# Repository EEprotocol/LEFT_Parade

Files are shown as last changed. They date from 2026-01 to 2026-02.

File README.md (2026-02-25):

[Japanese docs](./README_ja.md)
# LEFT Parade Project

This is a so-called *left-hand device*.  
You can also use it with your right hand.  
It is intended for situations where you use a pen display tablet or similar device with one of your hand and want to trigger macros with the other hand.

## TL;DR
navigate
## Specifications
- Connectivity is **Bluetooth only**. Wired connections are not supported.  
  This limitation is due to the ESP32-C3; however, by using a board such as the ESP32-S3 that supports USB HID, wired operation can be implemented.
- A battery can be installed (3.7 V Li-ion).  
  Connect it directly to the battery terminals on the surface of the ESP32-C3.
- Up to **80 different macros** can be configured using simultaneous key presses  
  (Arduino IDE is required to configure the macros).
- ~~To enable the above behavior, commands are sent **when the key switch is released**, not when it is pressed.~~  
- 2 mode implimented switched by the push switch in the rotary encoder:
    1. **Combination Mode**
        In this mode, you can assign 80 macros for the combination of multiple keys. The command is send to PC when you release the keys.
    2. **Fast Attack Mode**
        The number of assignment decline to 8 (same as the number of keys), but the command is send when you push the keys. You can use this mode if you mind the delay.

## Bill of Materials
| Component | Price (JPY) |
|:---|---:|
| PCB | 110 |
| Rotary encoder | 550 |
| Knob | 324 |
| ESP32-C3 | 1,080 |
| Keycap | 70 |
| Key socket | 160 |
| Key switch | 330 |
| Battery | 450 |
| (SN74HC139N) | 135 |
| DIP socket (8 × 2 rows) | 135 |
| **Total** | **3,344** |

## Installation  
### Hardware
#### Circuit Diagram
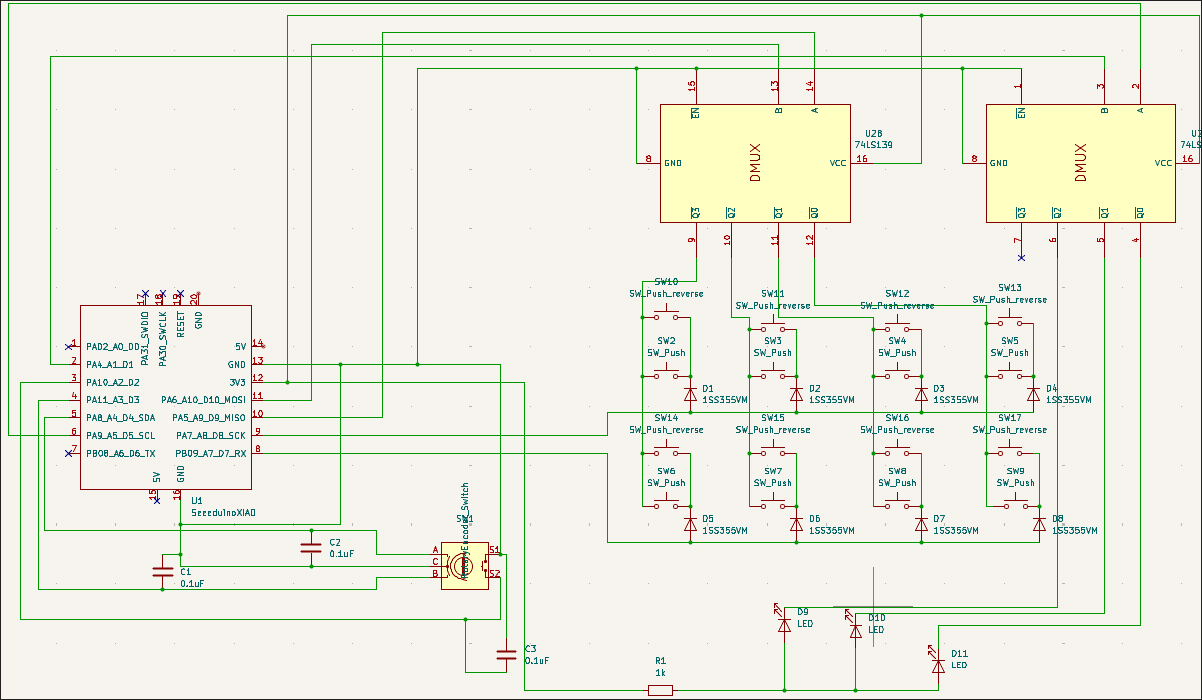
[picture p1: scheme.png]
circuit scheme Circuit Scheme

The annotation of the parts on the PCB corresponds to the circuit diagram.  
**I made a place for the LED D11, but system does not use it.**
#### soldering map
circuit soldering map
If you make this device as Left hand device, you solder on the parts surronded by **red and purple line**,
and If you make it as right hand device, solder on the parts with **purple and blue line**.
The component mounting side aligns with the side marked with the respective part indicators.

### Software
1. Install Arduino IDE on your PC, e.g.  
```yay -S arduino-ide```  

2. Install library [Mystfit/ESP32-BLE-CompositeHID](https://github.com/Mystfit/ESP32-BLE-CompositeHID).

3. Upload to `leftandmechv5_PCB/leftandmechv5_PCB.ino` to ESP32-C3.

## Macros
You can set the macro in the preamble of the `.ino` scripts.

```cpp
const uint8_t KC_SAVE[] = { 0x01, KEY_S };
const uint8_t KC_COPY[] = { 0x01, KEY_C };
const uint8_t KC_PASTE[] = { 0x01, KEY_V };
const uint8_t KC_DELETE[] = { 0x4c };
const uint8_t KC_m[] = { KEY_M };
const uint8_t KC_UNDO[] = { 0x01, KEY_Z };
const uint8_t KC_ESC[] = { KEY_ESC };
const uint8_t KC_UP[] = { KEY_UP };
const uint8_t KC_DOWN[] = { KEY_DOWN };
const uint8_t KC_LEFT[] = { KEY_LEFT };
const uint8_t KC_RIGHT[] = { KEY_RIGHT };
const uint8_t KC_PAGE_NEXT[] = { 0x01, KEY_RIGHT };
const uint8_t KC_PAGE_BACK[] = { 0x01, KEY_LEFT };
```
The list of `uint8_t` refers the operation s.t. Ctrl+S, ESC, or Delete. This list of macro is commonly used in the two mode.
In the list, terms of keys except the last term is regarded as modifier keys s.t. Alt, Ctrl or Shift.

### 1. Combination Mode
For this mode, you can set the assignment with `keymap[]`.
```cpp
const keyMapEntry keymap[] = {
  { 1, { KC_SAVE, 2 } },
  { 54, { KC_ESC, 1 } },
  { 4, { KC_COPY, 2 } },
  { 7, { KC_PASTE, 2 } },
  { 2, { KC_DELETE, 1 } },
  { 6, { KC_m, 1 } },
  { 28, { KC_UNDO, 2 } },
  { 18, { KC_UP, 1 } },
  { 9, { KC_DOWN, 1 } },
  { 27, { KC_LEFT, 1 } },
  { 3, { KC_RIGHT, 1 } },
  { 8, { KC_PAGE_NEXT, 2 } },
  { 20, { KC_PAGE_BACK, 2 } }
};
```

The first number refers the keyID of the combinaiton, second string refers the macro which you defined above and the last number refers the number of the element of the list of the macro. You can calculate the keyID as following:

assignment key_assign

2 refers the upper key, 1 refers the lower key, 0 refers no pushed.
In this mode, it is prohibited to push 2 keys in a column.

### 2. Fast Attack Mode
```cpp
const keyMapEntry direct_key[] = {
  { 1, { KC_LEFT, 1 } },
  { 2, { KC_UP, 1 } },
  { 3, { KC_DOWN, 1 } },
  { 5, { KC_RIGHT, 1 } }
};
```

The key ID which plades the first number corresponds to the following assignment:

assignment key_assign

## Todo
- [x] Impliment the GAME mode which sends commnad when keys are pushed
- [x] Fabricate a PCB
- [ ] Prepare the other version: RIGHT Parade

## Special Thanks
- [Mystfit/ESP32-BLE-CompositeHID](https://github.com/Mystfit/ESP32-BLE-CompositeHID)
- [freerouting/freerouting](https://github.com/freerouting/freerouting?tab=readme-ov-file)

## Contact
If you have something to ask, please mail to [keik4656@gmail.com](keik4656@gmail.com).

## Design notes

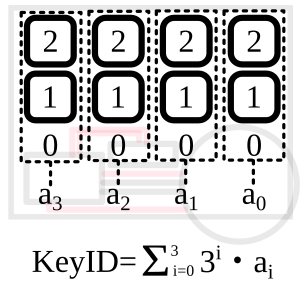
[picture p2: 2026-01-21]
assign.png

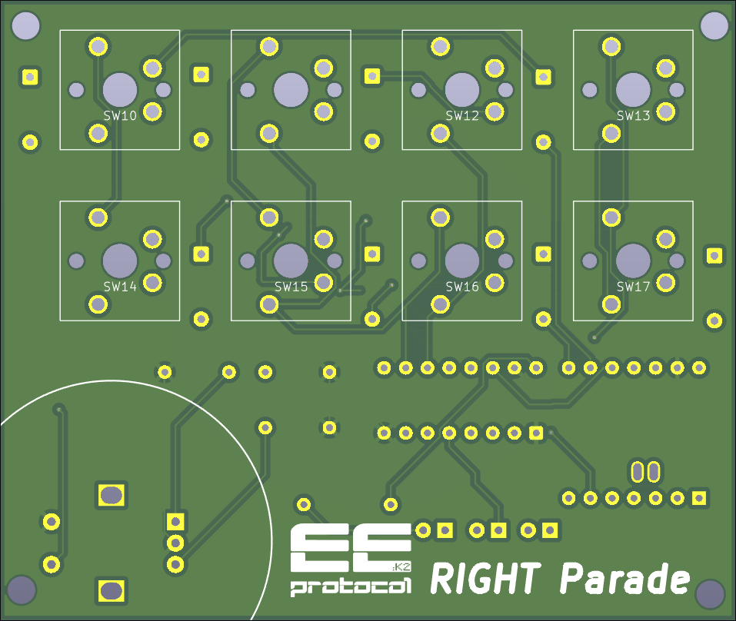
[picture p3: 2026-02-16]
2026-02-15-222912_hyprshot.png

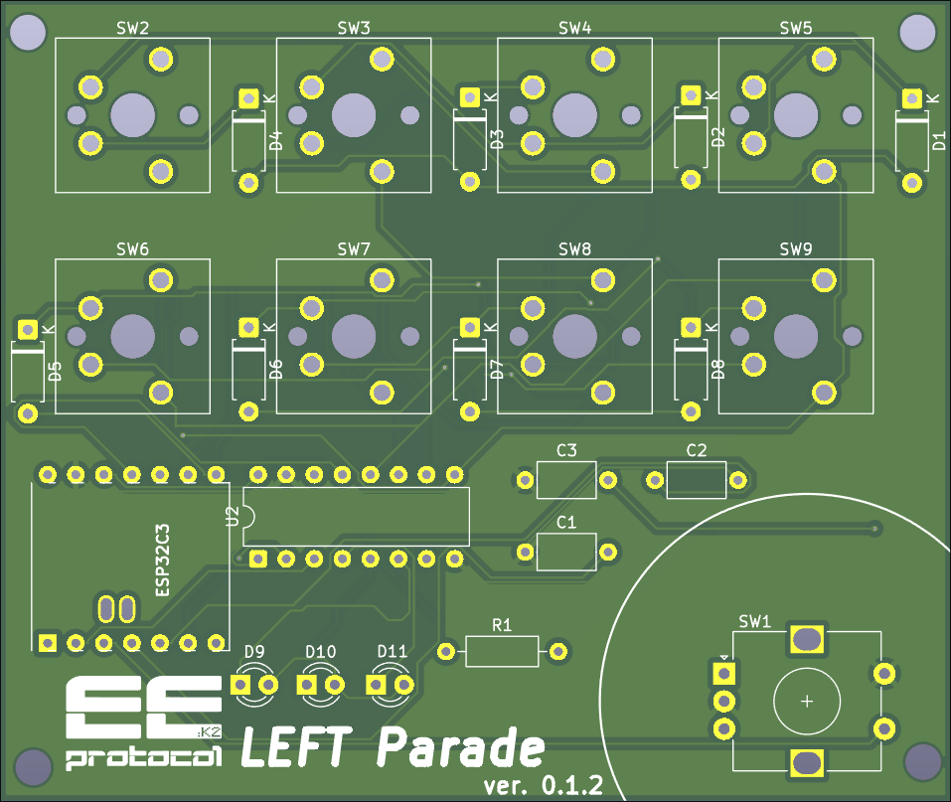
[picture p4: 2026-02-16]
2026-02-15-222832_hyprshot.png

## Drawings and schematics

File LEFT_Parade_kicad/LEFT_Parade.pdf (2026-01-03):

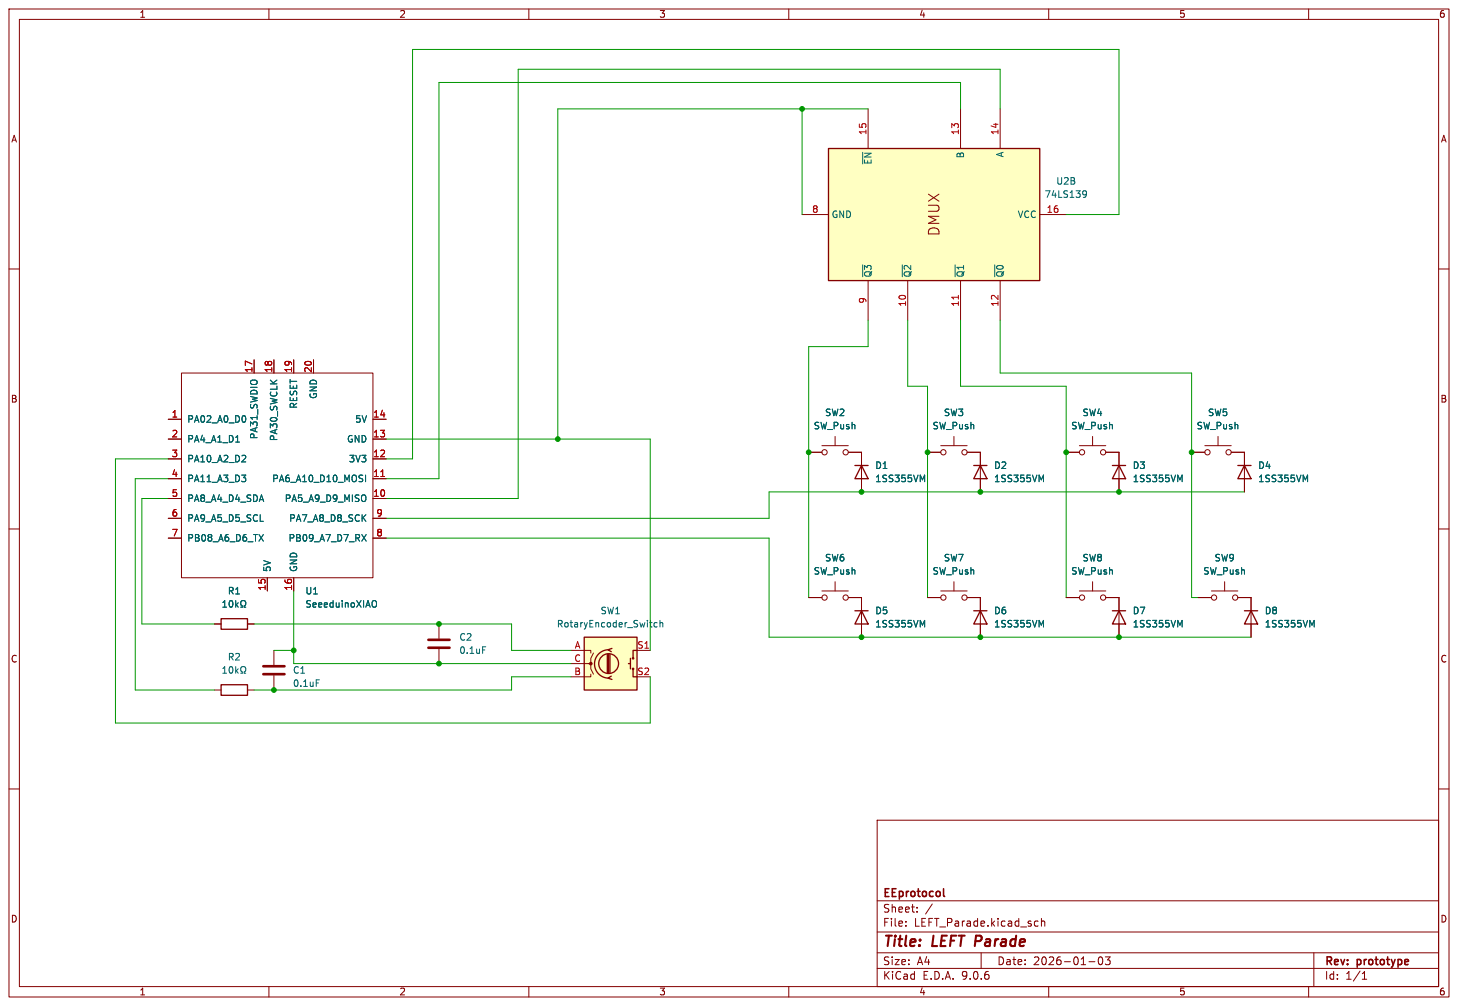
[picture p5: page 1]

Id: 1/1 Title: LEFT Parade

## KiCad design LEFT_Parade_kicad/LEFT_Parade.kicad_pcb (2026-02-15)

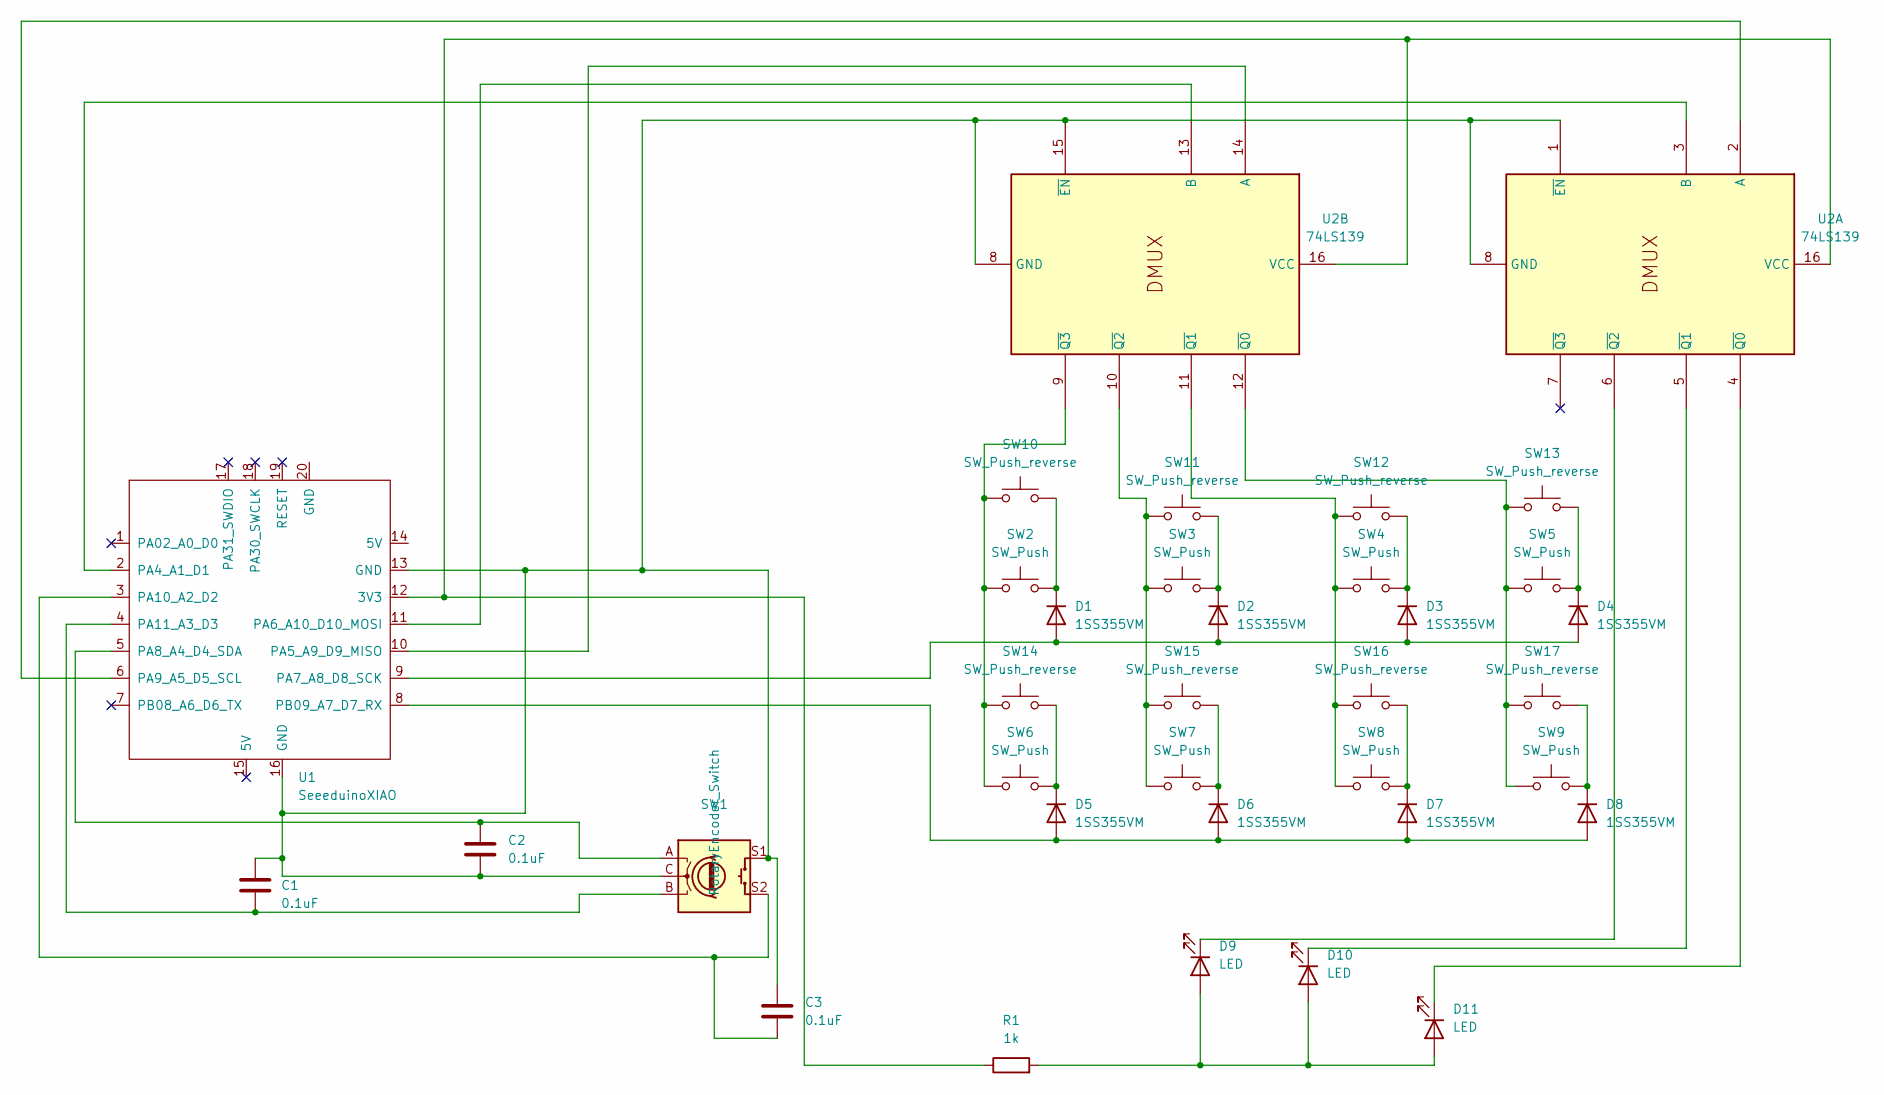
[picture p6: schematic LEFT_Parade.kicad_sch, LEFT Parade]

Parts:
C1, C2, C3: 0.1uF; C_Axial_L5.1mm_D3.1mm_P7.50mm_Horizontal
D1, D2, D3, D4, D5, D6, D7, D8: 1SS355VM; D_A-405_P7.62mm_Horizontal
D9, D10, D11: LED; LED_D3.0mm_Clear
R1: 1k; R_Axial_DIN0207_L6.3mm_D2.5mm_P10.16mm_Horizontal
SW1: RotaryEncoder_Switch; RotaryEncoder_Alps_EC12E-Switch_Vertical_H20mm
SW2, SW3, SW4, SW5, SW6, SW7, SW8, SW9: SW_Push; SW_Cherry_MX_1.00u_PCB
SW10, SW11, SW12, SW13, SW14, SW15, SW16, SW17: SW_Push_reverse; SW_Cherry_MX_1.00u_PCB_reverse
U1: SeeeduinoXIAO; ESP32C3_Footprint
U2: 74LS139; CERDIP-16_W7.62mm_SideBrazed

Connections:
unnamed: D1.2 (A), D2.2 (A), D3.2 (A), D4.2 (A), U1.9 (PA7_A8_D8_SCK)
unnamed: D1.1 (K), SW2.2, SW10.2
unnamed: D2.1 (K), SW3.2, SW11.2
unnamed: D3.1 (K), SW4.2, SW12.2
unnamed: D4.1 (K), SW5.2, SW13.2
unnamed: D5.2 (A), D6.2 (A), D7.2 (A), D8.2 (A), U1.8 (PB09_A7_D7_RX)
unnamed: D5.1 (K), SW6.2, SW14.2
unnamed: D6.1 (K), SW7.2, SW15.2
unnamed: D7.1 (K), SW8.2, SW16.2
unnamed: D8.1 (K), SW9.2, SW17.2
unnamed: D9.1 (K), U2.6 (~Q2)
unnamed: D9.2 (A), D10.2 (A), D11.2 (A), R1.2
unnamed: D10.1 (K), U2.5 (~Q1)
unnamed: D11.1 (K), U2.4 (~Q0)
unnamed: R1.1, U1.12 (3V3), U2.16 (VCC)
unnamed: U1.2 (PA4_A1_D1), U2.3 (B)
unnamed: U1.10 (PA5_A9_D9_MISO), U2.14 (A)
unnamed: U1.11 (PA6_A10_D10_MOSI), U2.13 (B)
unnamed: C2.1, SW1.A, U1.5 (PA8_A4_D4_SDA)
unnamed: U1.6 (PA9_A5_D5_SCL), U2.2 (A)
unnamed: C3.2, SW1.S2, U1.3 (PA10_A2_D2)
unnamed: C1.2, SW1.B, U1.4 (PA11_A3_D3)
unnamed: C1.1, C2.2, C3.1, SW1.C, SW1.S1, U1.13 (GND), U1.16 (GND), U2.1 (~EN), U2.8 (GND), U2.15 (~EN)
unnamed: SW5.1, SW9.1, SW13.1, SW17.1, U2.12 (~Q0)
unnamed: SW4.1, SW8.1, SW12.1, SW16.1, U2.11 (~Q1)
unnamed: SW3.1, SW7.1, SW11.1, SW15.1, U2.10 (~Q2)
unnamed: SW2.1, SW6.1, SW10.1, SW14.1, U2.9 (~Q3)

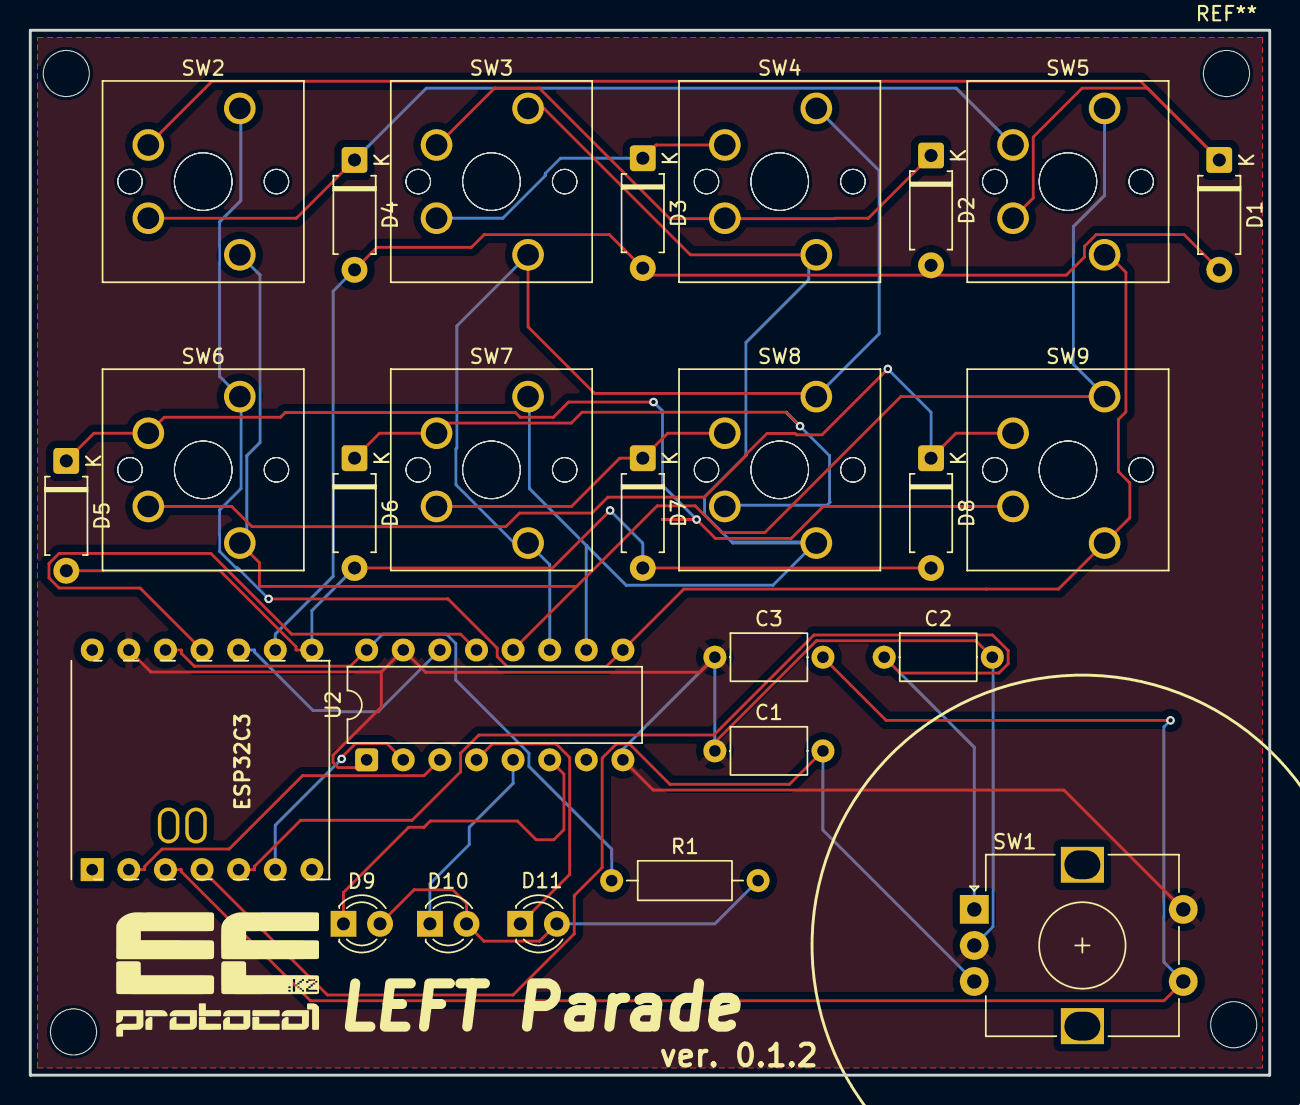
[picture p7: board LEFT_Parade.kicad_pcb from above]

Board: 2 copper layers, 86.0 x 72.5 mm, 34 parts (0 on the bottom side), 27 nets.

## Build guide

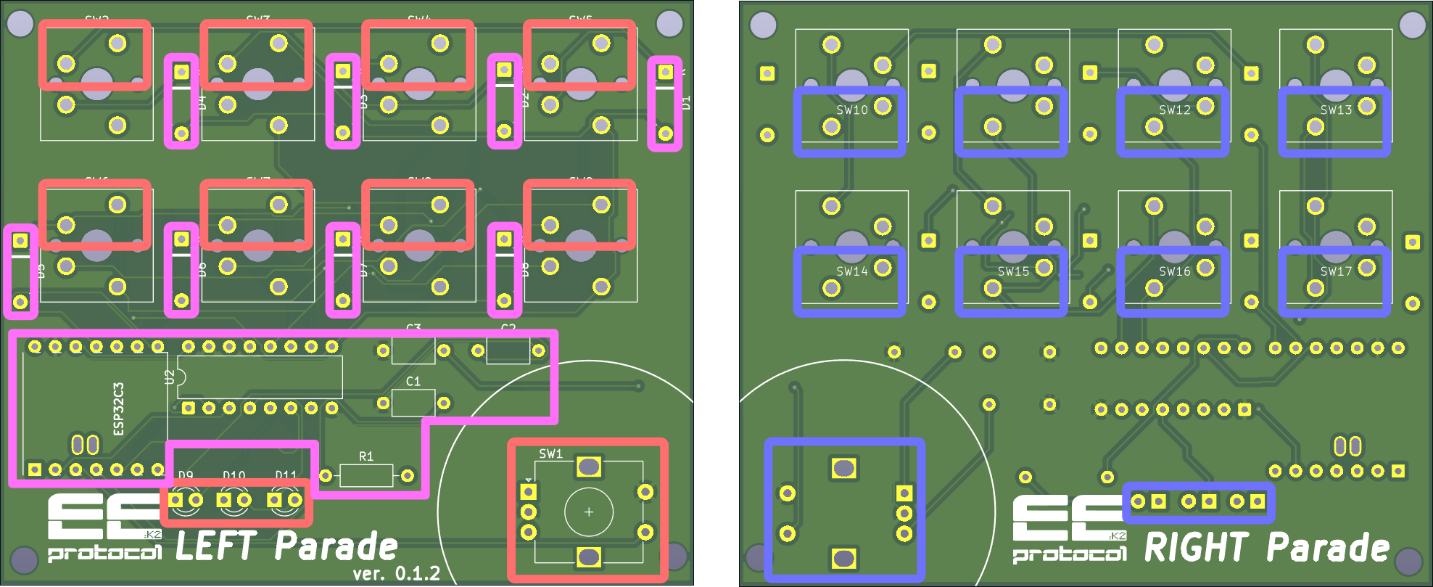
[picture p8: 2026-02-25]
solder.png

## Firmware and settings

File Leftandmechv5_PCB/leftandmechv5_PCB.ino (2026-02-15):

#include <BleConnectionStatus.h>

#include <BleCompositeHID.h>
#include <KeyboardDevice.h>
#include <MouseDevice.h>


KeyboardDevice* keyboard;
MouseDevice* mouse;
BleCompositeHID compositeHID("LEFT Parade", "EEprotocol", 100);

struct KeyCombo {
  const uint8_t* keys;
  uint8_t length;
};
struct keyMapEntry {
  int id;
  KeyCombo combo;
};
const uint8_t KC_SAVE[] = { 0x01, KEY_S };
const uint8_t KC_COPY[] = { 0x01, KEY_C };
const uint8_t KC_PASTE[] = { 0x01, KEY_V };
const uint8_t KC_DELETE[] = { 0x4c };
const uint8_t KC_m[] = { KEY_M };
const uint8_t KC_UNDO[] = { 0x01, KEY_Z };
const uint8_t KC_REDO[] = { 0x01, KEY_Y };
const uint8_t KC_CUT[] = { 0x01, KEY_X };
const uint8_t KC_ESC[] = { KEY_ESC };
const uint8_t KC_UP[] = { KEY_UP };
const uint8_t KC_DOWN[] = { KEY_DOWN };
const uint8_t KC_LEFT[] = { KEY_LEFT };
const uint8_t KC_RIGHT[] = { KEY_RIGHT };
const uint8_t KC_PAGE_NEXT[] = { 0x01, KEY_RIGHT };
const uint8_t KC_PAGE_BACK[] = { 0x01, KEY_LEFT };
const uint8_t KC_SPACE[] = { KEY_SPACE };
const uint8_t KC_PARTIALSHOT[]={KEY_MOD_LMETA,KEY_MOD_LSHIFT,KEY_S};

const keyMapEntry keymap[] = {
 {  1, { KC_SAVE,      2 } },
{  2, { KC_DELETE,    1 } },
{  3, { KC_RIGHT,     1 } },
{  6, { KC_m,         1 } },
{  8, { KC_PAGE_NEXT, 2 } },
{  9, { KC_DOWN,      1 } },
{ 12, { KC_SPACE,     1 } },
{ 18, { KC_UP,        1 } },
{ 20, { KC_PAGE_BACK, 2 } },
{26,{KC_PARTIALSHOT,3}},
{ 27, { KC_LEFT,      1 } },
{ 28, { KC_PASTE,     2 } },
{ 30, { KC_COPY,      2 } },
{ 33, { KC_REDO,      2 } },
{ 36, { KC_CUT,       1 } },
{ 45, { KC_UNDO,      2 } },
{ 54, { KC_ESC,       1 } }
};
const keyMapEntry direct_key[] = {
  { 1, { KC_LEFT, 1 } },
  { 2, { KC_UP, 1 } },
  { 3, { KC_DOWN, 1 } },
  { 5, { KC_RIGHT, 1 } }
};
const int KEYMAP_SIZE = sizeof(keymap) / sizeof(keymap[0]);
const int DIRECT_KEY_SIZE = sizeof(direct_key) / sizeof(direct_key[0]);
const int C1 = D7;
const int C2 = D8;
const int mult1 = D9;
const int mult2 = D10;
const int rota = D4;
const int rotb = D3;
const int rotsw = D2;
const int mult2_1 = D5;
const int mult2_2 = D1;


int stop = 0;
int dir = 0;
unsigned long lastActivityTime = 0;               // 最後にボタンが押された時刻を記録
const unsigned long inactivityThreshold = 60000;  // 1分（60000ミリ秒）操作がない場合にスリープするよう設定
int forward = 0;
int back = 0;
int rot_st = 0;
int total = 0;
int prev_forward = 0;
int prev_back = 0;
bool prev_result[8] = { 0 };
RTC_DATA_ATTR int mode = 1;


bool prev_direct_pressed = false;
bool direct_pressed = false;
void sendKeyCombo(const KeyCombo& combo) {

  // --- modifier press ---
  for (int i = 0; i < combo.length; i++) {
    uint8_t k = combo.keys[i];
    if (k == 0x01 || k == 0x02 || k == 0x04 || k == 0x08) {
      keyboard->modifierKeyPress(k);
    }
  }

  // --- normal key press ---
  for (int i = 0; i < combo.length; i++) {
    uint8_t k = combo.keys[i];
    if (!(k == 0x01 || k == 0x02 || k == 0x04 || k == 0x08)) {
      keyboard->keyPress(k);
    }
  }

  keyboard->sendKeyReport();

  // --- normal key release ---
  for (int i = 0; i < combo.length; i++) {
    uint8_t k = combo.keys[i];
    if (!(k == 0x01 || k == 0x02 || k == 0x04 || k == 0x08)) {
      keyboard->keyRelease(k);
    }
  }

  // --- modifier release ---
  for (int i = 0; i < combo.length; i++) {
    uint8_t k = combo.keys[i];
    if (k == 0x01 || k == 0x02 || k == 0x04 || k == 0x08) {
      keyboard->modifierKeyRelease(k);
    }
  }

  keyboard->sendKeyReport();
}

void sendDirectKeyCombo(const KeyCombo& combo, char order) {
  if (order == 'p') {
    Serial.println("mode1:pushed");
    // --- modifier press ---
    for (int i = 0; i < combo.length; i++) {
      uint8_t k = combo.keys[i];
      if (k == 0x01 || k == 0x02 || k == 0x04 || k == 0x08) {
        keyboard->modifierKeyPress(k);
      }
    }

    // --- normal key press ---
    for (int i = 0; i < combo.length; i++) {
      uint8_t k = combo.keys[i];
      if (!(k == 0x01 || k == 0x02 || k == 0x04 || k == 0x08)) {
        keyboard->keyPress(k);
      }
    }

    keyboard->sendKeyReport();
  }

  if (order == 'r') {
    for (int k = 0; k < 100; k++) {


      Serial.println("mode2:released");
    }
    // --- normal key release ---
    for (int i = 0; i < combo.length; i++) {
      uint8_t k = combo.keys[i];
      if (!(k == 0x01 || k == 0x02 || k == 0x04 || k == 0x08)) {
        keyboard->keyRelease(k);
      }
    }

    // --- modifier release ---
    for (int i = 0; i < combo.length; i++) {
      uint8_t k = combo.keys[i];
      if (k == 0x01 || k == 0x02 || k == 0x04 || k == 0x08) {
        keyboard->modifierKeyRelease(k);
      }
    }

    keyboard->sendKeyReport();
  }
}

bool execKeymap(int id) {
  for (int i = 0; i < KEYMAP_SIZE; i++) {
    if (keymap[i].id == id) {
      sendKeyCombo(keymap[i].combo);
      return true;  // 実行成功
    }
  }
  return false;  // 該当IDなし
}

bool execDirectAttack(int id, char order) {
  for (int i = 0; i < DIRECT_KEY_SIZE; i++) {
    if (direct_key[i].id == id) {
      sendDirectKeyCombo(direct_key[i].combo, order);
      return true;  // 実行成功
    }
  }
  return false;  // 該当IDなし
}

void checkPos() {
  int reada = digitalRead(rota);
  int readb = digitalRead(rotb);

  if (readb == reada) {
    //Serial.println("STOP");
  } else {
    if (reada > readb) {
      dir = stop;
    } else {
      dir = -1 * stop;
    }
  }
}
void pushrotsw() {
  if (digitalRead(rotsw) == 0) {
    rot_st = 1;
    Serial.println("rotsw_pushed");
    if (mode == 1) {
      mode = 2;
    } else if (mode == 2) {
      mode = 1;
    }
  }
}




void allPinsHiZ() {
  pinMode(mult1, OUTPUT);
  pinMode(mult2, OUTPUT);
  pinMode(C1, INPUT_PULLUP);
  pinMode(C2, INPUT_PULLUP);

  digitalWrite(mult1, LOW);
  digitalWrite(mult2, LOW);
  delayMicroseconds(10);
}

void scanMatrix(int k[8]) {
  allPinsHiZ();
  for (int i = 0; i < 4; i++) {
    digitalWrite(mult1, i & 1);
    digitalWrite(mult2, (i >> 1) & 1);
    delayMicroseconds(3);
    k[2 * i] = (digitalRead(C2) == LOW);
    k[2 * i + 1] = (digitalRead(C1) == LOW);
  }
}                                       
void setup() {
  Serial.begin(115200);
  pinMode(rota, INPUT_PULLUP);
  pinMode(rotb, INPUT_PULLUP);
  pinMode(rotsw, INPUT_PULLUP);
  pinMode(mult2_1, OUTPUT);
  pinMode(mult2_2, OUTPUT);
  Serial.begin(115200);
  attachInterrupt(digitalPinToInterrupt(rota), checkPos, CHANGE);
  attachInterrupt(digitalPinToInterrupt(rotb), checkPos, CHANGE);
  attachInterrupt(digitalPinToInterrupt(rotsw), pushrotsw, CHANGE);
  // Set up keyboard
  KeyboardConfiguration keyboardConfig;
  keyboardConfig.setAutoReport(false);
  keyboard = new KeyboardDevice(keyboardConfig);

  // Set up mouse
  MouseConfiguration mouseConfig;
  mouseConfig.setAutoReport(false);
  mouse = new MouseDevice(mouseConfig);

  // Add both devices to the composite HID device to manage them
  compositeHID.addDevice(keyboard);
  compositeHID.addDevice(mouse);

  // Start the composite HID device to broadcast HID reports
  compositeHID.begin();
  esp_deep_sleep_enable_gpio_wakeup(
    BIT(4), ESP_GPIO_WAKEUP_GPIO_LOW);

  delay(3000);
}


bool operated = 0;
bool sleeping = false;
unsigned long last_operated = 0;
bool recorder[8] = { 0 };
int sum = 0;
int prevsum = 0;
void loop() {
  digitalWrite(mult2_2, mode & 1);
  digitalWrite(mult2_1, (mode >> 1) & 1);
  int keys[8] = { 0 };
  scanMatrix(keys);
  bool flag_pushed = 0;
  int bitnum = 0;
  Serial.print("mode:");
  Serial.println(mode);
  int tmp[8]={0};
  for(int i=0;i<8;i++){
    tmp[7-i]=keys[i];
  }
  for(int i=0;i<4;i++){
    int j=tmp[2*i];
    tmp[2*i]=tmp[2*i+1];
    tmp[2*i+1]=j;
  }
  for(int i=0;i<8;i++){
    keys[i]=tmp[i];
  }


  for (int i = 0; i < 8; i++) {
    Serial.print(keys[i] ? "1 " : "0 ");
    bitnum += keys[i];
    flag_pushed = (flag_pushed || keys[i]);
  }
  Serial.println();


  if (flag_pushed == 1) {
    for (int i = 0; i < 8; i++) {
      recorder[i] = (recorder[i] || keys[i]);
      Serial.print(recorder[i]);
    }
    Serial.println();
  } else {
    sum = 0;
    for (int i = 0; i < 4; i++) {
      int tmp = 2 * recorder[2 * i] + recorder[2 * i + 1];
      sum += pow(3, 3 - i) * tmp;
      if (recorder[2 * i] == 1 && recorder[2 * i + 1] == 1) {
        sum = -1;
        break;
      }
    }
    Serial.print("sum= ");
    Serial.println(sum);
    for (int i = 0; i < 8; i++) {
      recorder[i] = 0;
    }
    if (sum != 0) {
      prevsum = sum;
    }
    Serial.print("prevsum= ");
    Serial.println(prevsum);
  }

  int reada = digitalRead(rota);
  int readb = digitalRead(rotb);
  int newstop = 0;

  if (reada == readb) {
    if (readb == 0) {
      newstop = -1;
    } else {
      newstop = 1;
    }
    if (dir != 0 && newstop != stop) {
      if (dir == 1) {
        //Serial.println("UP");
        total++;
        forward = 1;
      } else if (dir == -1) {
        total--;
        back = 1;
        //Serial.println("DOWN");
      }
      Serial.println(total);
      dir = 0;
    }
    stop = newstop;
  }

  for (int i = 0; i < 8; i++) {
    if (keys[i] == 1) {
      operated = true;
    }
  }
  if (compositeHID.isConnected()) {
    if(mode==0){
      mode=1;
    }
    if (mode == 1 && sum != 0) {
      execKeymap(sum);
      sum = 0;
    } else if (mode == 2) {
      direct_pressed = false;
      for (int i = 0; i < 8; i++) {
        if (keys[i] == 1 && prev_result[i] == 0) {

          execDirectAttack(i, 'p');
          prev_result[i]=1;
        }
      }
      for (int i = 0; i < 8; i++) {
        if (keys[i] == 0 && prev_result[i] == 1) {
          for (int k = 0; k < 10000; k++) {

            Serial.println("mode2:released");

          }
          execDirectAttack(i, 'r');
          prev_result[i]=0;
        }
      }
    }
    if (forward == 1) {
      operated = true;

      if (millis() - prev_forward < 200) {
        mouse->mouseMove(0, 0, 0, 3);
        mouse->sendMouseReport();
      }
      mouse->mouseMove(0, 0, 0, 3);
      mouse->sendMouseReport();

      prev_forward = millis();
    }
    if (back == 1) {
      operated = true;

      if (millis() - prev_back < 200) {
        mouse->mouseMove(0, 0, 0, -3);
        mouse->sendMouseReport();
      }
      mouse->mouseMove(0, 0, 0, -3);
      mouse->sendMouseReport();

      prev_back = millis();
    }
    if (rot_st) {
      operated = true;
      Serial.println("SW pushed!");
      lastActivityTime = millis();

      rot_st = 0;
    }
  }else{
    mode=0;
  }
  Serial.println(operated);
  Serial.print("last_operated: ");
  Serial.println(last_operated);
  if (forward || back || operated) {
    Serial.print("forward= ");
    Serial.print(forward);
    Serial.print(" back= ");
    Serial.print(back);
    Serial.print(" operated= ");
    Serial.println(operated);
    last_operated = millis();
    operated = false;
    forward = 0;
    back = 0;

  } else {
    if (millis() - last_operated > 300000) {
      digitalWrite(mult2_1, 0);
      digitalWrite(mult2_2, 0);
      delay(1000);
      Serial.println("into deep sleep");
      Serial.flush();
      esp_deep_sleep_start();
    }
  }


  delay(20);
}

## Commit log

2026-01-03 [Add] kicad project file
    [LEFT_Parade.kicad_pcb, LEFT_Parade.kicad_sch]
2026-01-12 [Add] game mode
    [LEFT_Parade.kicad_sch]
2026-01-19 [Modify] thankyou...
    [LEFT_Parade.dsn, LEFT_Parade.kicad_pcb, LEFT_Parade.kicad_sch]
2026-01-21 [Modify] Readme.md
    [LEFT_Parade-B_Cu.gbr, LEFT_Parade-B_Mask.gbr, LEFT_Parade-B_Paste.gbr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]
2026-02-15 [Modify] Version UP
    [LEFT_Parade-B_Cu.gbr, LEFT_Parade-B_Mask.gbr, LEFT_Parade-B_Paste.gbr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]
2026-02-20 [Modify] solder.svg
